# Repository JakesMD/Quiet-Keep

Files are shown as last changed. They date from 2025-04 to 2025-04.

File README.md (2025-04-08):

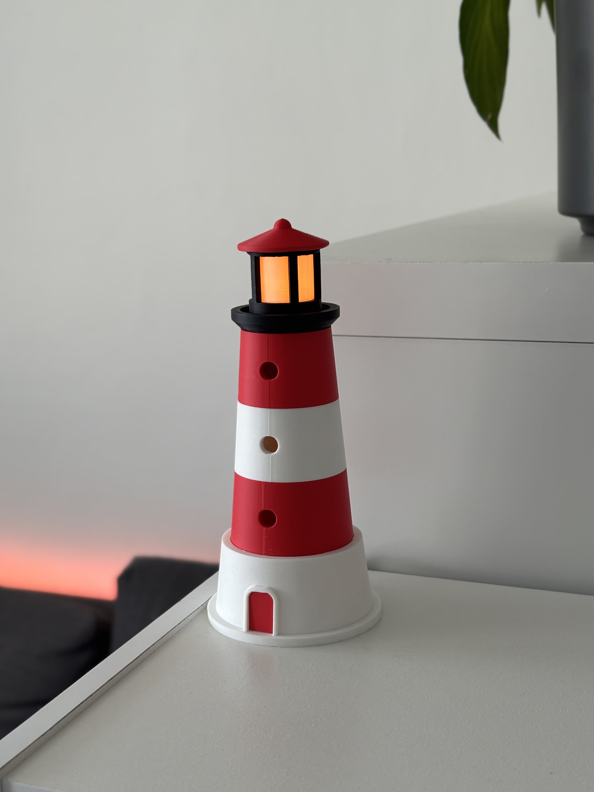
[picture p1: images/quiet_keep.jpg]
Quiet Keep


# Quiet Keep

A noise activated lighthouse to help kids find their inside voices.

## 🕹️ Usage

- Place the lighthouse high up on a shelf away from direct sound sources.
- When the lighthouse senses that the general noise level is too high, it will beep.
- If the lighthouse is beeping prematurely, turn the trimpot to the left to increase the sensitivity.
- If the lighthouse is not beeping at all, turn the trimpot to the right to decrease the sensitivity.

## 🔨 Make your own
### 🧱 Parts
- Arduino Nano with USB-C port
- Orange or yellow 5mm LED
- GY-MAX4466 microphone
- 10k Ohm trimpot (103)
- Piezo buzzer
- A bunch of wires

### 🧵 Wiring
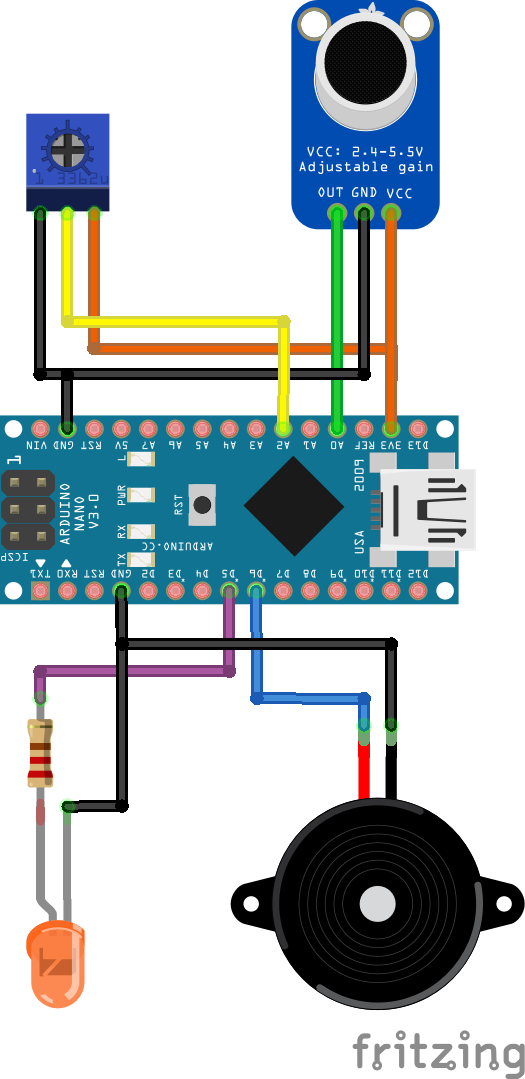
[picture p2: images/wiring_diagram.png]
Wiring Diagram


### 🏗️ Assembly
[quiet_keep.step](quiet_keep.step) contains the models of the 3D-printed parts.

I printed the bottom of the roof in white to maximize the brightness.

**Printer:** Bambu Lab A1 with AMS

**Nozzle:** 0.4mm

**Preset:** 0.20mm Standard @BBL A1 with supports enabled

**Filaments:**
- Bambu Lab PLA Matte Ivory White (11100)
- Bambu Lab PLA Matte Scarlet Red (11200)
- Bambu Lab PLA Matte Charcoal (11101)

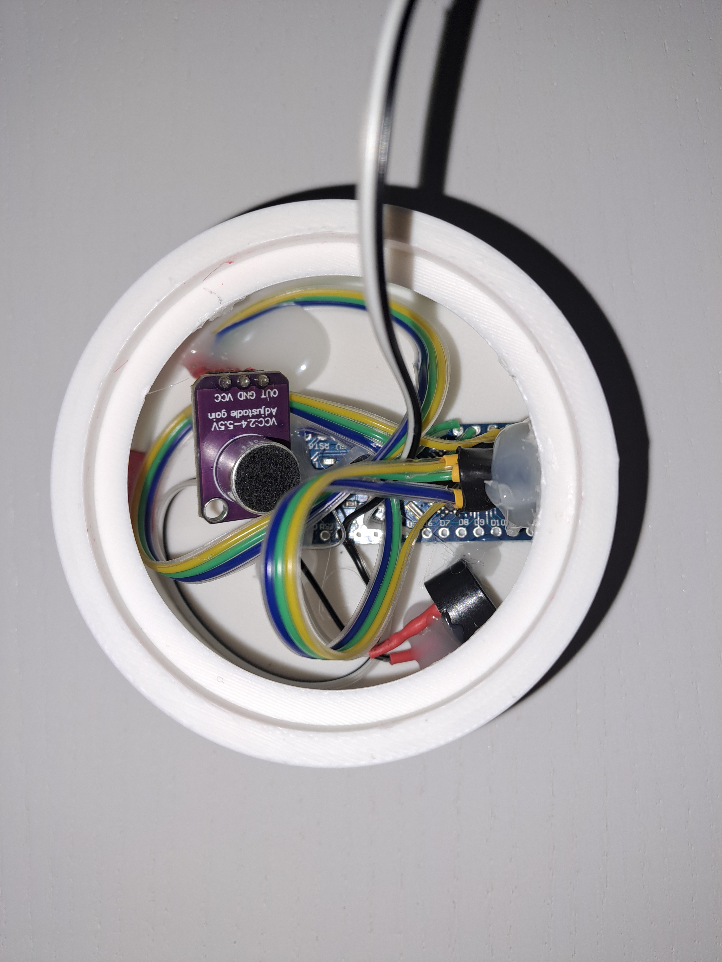
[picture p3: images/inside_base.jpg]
inside base

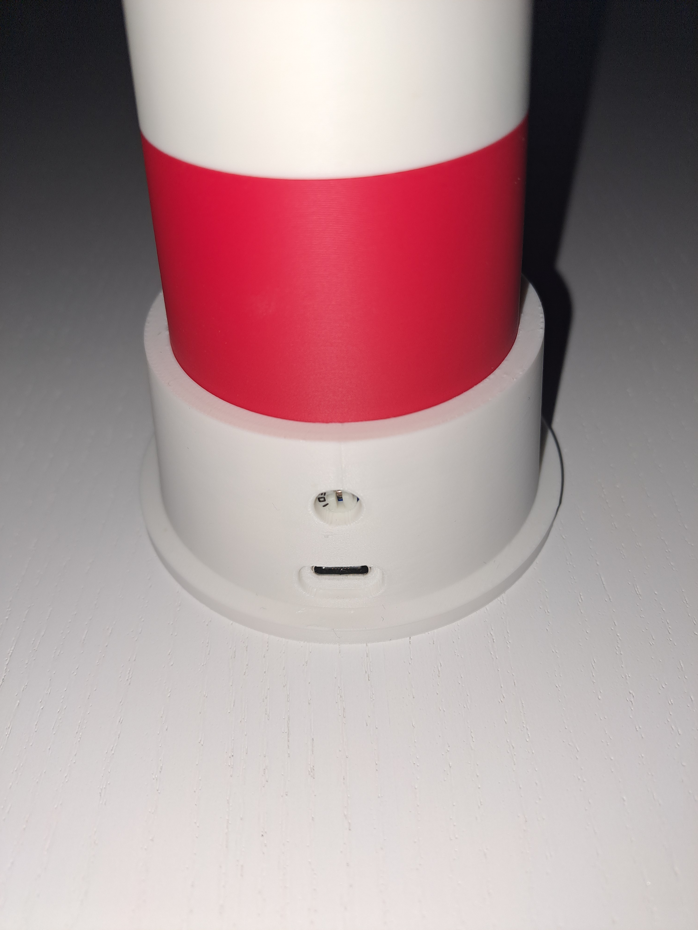
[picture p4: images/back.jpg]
back

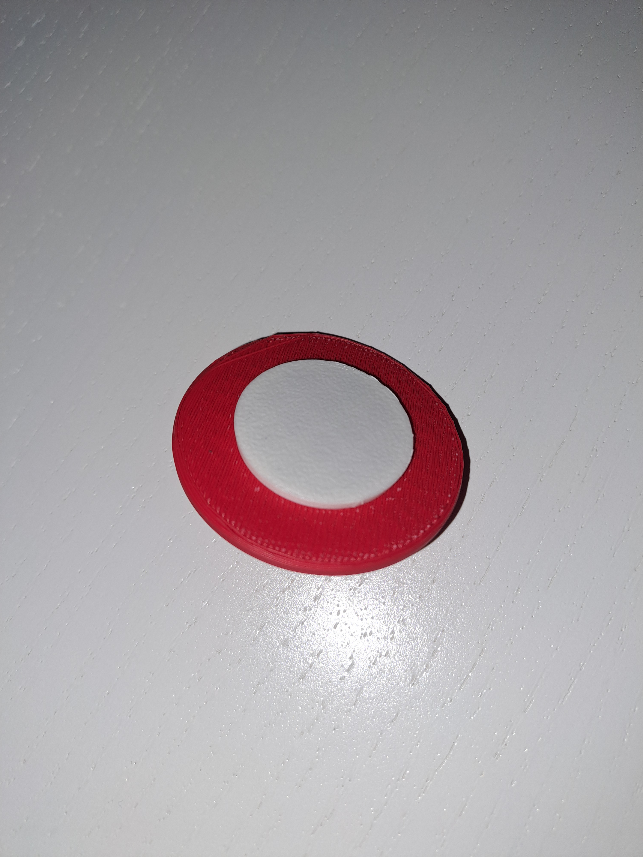
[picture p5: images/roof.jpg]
roof


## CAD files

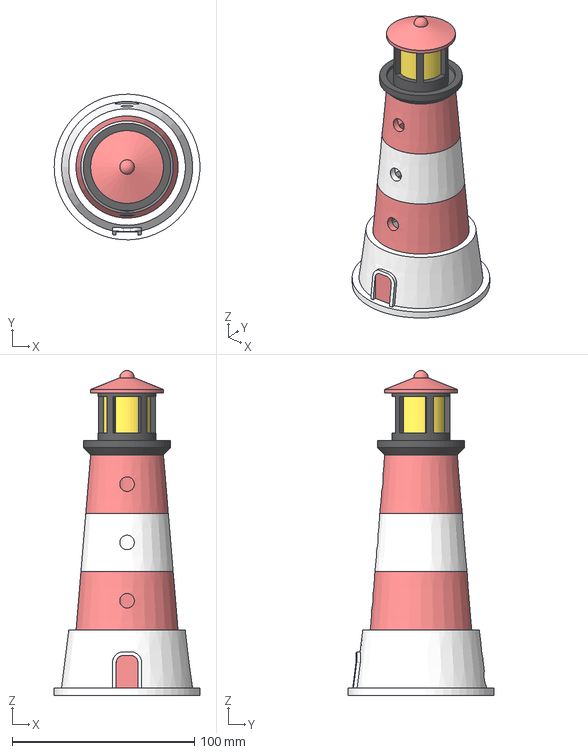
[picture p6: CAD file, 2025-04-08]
quiet_keep.step
79.9 x 80.0 x 178.4 mm

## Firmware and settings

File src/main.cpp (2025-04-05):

#include <Arduino.h>

#include "buzzer.h"
#include "config.h"
#include "fade_led.h"
#include "mic.h"
#include "pot.h"

QMic mic(MIC_PIN, SAMPLE_WINDOW);
QFadeLED led(LED_PIN);
QPot sensitivityPot(POT_SENSITIVITY_PIN, 400, 0);
QBuzzer buzzer(BUZZER_PIN, BUZZER_FREQUENCY, FAST_FADE_DURATION);

uint16_t volume = 0;
uint16_t accumulation = 0;
uint16_t accumulationTriggerVolume;
unsigned long currentMillis;
unsigned long startMillis;

uint16_t calculateAccumulation(uint16_t volume, uint16_t currentAccumulation, uint16_t accumulationTriggerVolume) {
    uint16_t newAccumulation = 0;

    if (volume >= accumulationTriggerVolume && currentAccumulation < ACCUMULATION_LIMIT) {
        newAccumulation = currentAccumulation + ATTACK;
    } else if (volume < accumulationTriggerVolume && currentAccumulation > 0) {
        newAccumulation = currentAccumulation - RELEASE;
    }

    if (newAccumulation > ACCUMULATION_LIMIT) newAccumulation = ACCUMULATION_LIMIT;

    return newAccumulation;
}

void plotData(uint16_t volume, uint16_t accumulation, uint16_t accumulationTriggerVolume) {
    Serial.print("Volume:");
    Serial.print(volume);
    Serial.print("\t");
    Serial.print("Accumulation:");
    Serial.print(accumulation);
    Serial.print("\t");
    Serial.print("Accumulation_Trigger_Volume:");
    Serial.print(accumulationTriggerVolume);
    Serial.print("\t");
    Serial.print("Accumulation_Limit:");
    Serial.println(ACCUMULATION_LIMIT);
}

void setup() {
    Serial.begin(115200);
    currentMillis = millis();
}

void loop() {
    startMillis = currentMillis;

    while (currentMillis - startMillis < SAMPLE_WINDOW) {
        led.loop(currentMillis);
        mic.loop();
        currentMillis = millis();
    }

    volume = mic.volume();
    accumulationTriggerVolume = sensitivityPot.read();
    accumulation = calculateAccumulation(volume, accumulation, accumulationTriggerVolume);

    plotData(volume, accumulation, accumulationTriggerVolume);

    if (accumulation >= ACCUMULATION_LIMIT) {
        led.setFadeDuration(FAST_FADE_DURATION);

        while (buzzer.beepCount() < 3) {
            currentMillis = millis();
            led.loop(currentMillis);
            buzzer.loop(currentMillis);
        }

        buzzer.reset();
        led.setFadeDuration(MEDIUM_FADE_DURATION);
        accumulation = ACCUMULATION_RESET_VALUE;
    } else if (accumulation > 0) {
        led.setFadeDuration(MEDIUM_FADE_DURATION);
    } else {
        led.setFadeDuration(SLOW_FADE_DURATION);
    }
}

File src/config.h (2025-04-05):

#define MIC_PIN A0
#define POT_SENSITIVITY_PIN A1
#define POT_DURATION_PIN A2
#define LED_PIN 5
#define BUZZER_PIN 6

#define SAMPLE_WINDOW 50

#define ATTACK 3
#define RELEASE 1

#define FAST_FADE_DURATION 500
#define MEDIUM_FADE_DURATION 500
#define SLOW_FADE_DURATION 2000

#define BUZZER_FREQUENCY 660

#define ACCUMULATION_LIMIT 100
#define ACCUMULATION_RESET_VALUE 25

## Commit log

2025-04-01 🎉 Initial commit
2025-04-01 ✨ Create wiring diagram
    [wiring_diagram.fzz]
2025-04-05 🐛 Fix mic picking up buzzer sound
    [config.h, main.cpp]
2025-04-05 🔥 Remove duration pot
    [wiring_diagram.fzz]
2025-04-05 📝 Add usage section
2025-04-08 📌 Move buzzer pin to D6
    [wiring_diagram.fzz]
2025-04-08 ⬆️ Upload images
2025-04-08 ⬆️ Upload 3D model
    [quiet_keep.step]
2025-04-08 📝 Add parts and assembly sections to README
